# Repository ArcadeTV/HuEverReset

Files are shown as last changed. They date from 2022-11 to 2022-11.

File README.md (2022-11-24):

## HuEverReset
InGame-Reset for PC Engine with support for TurboEverdrive v1-v2.5

_*Important!*_ - Please consider waiting until everything is confirmed working.

### v20221109 / ArcadeTV

---

#### Description:
This enables an InGame-Reset by pressing a button-combo on the controller that also works with TurboEverdrive to get back to the menu.
It is designed for the white japanese PC Engine console but can be easily adapted to any PC Engine system if you know which pins of the controller-input-socket to connect to the pcb. Optionally you can use a piezo speaker for acoustic feedback upon triggering a reset.

---

#### Parts

| Part | Value | Device | Package |
| :--- | :--- | :--- | :--- |
| CB1  | 100nF | C-USC0805 | C0805 |
| C1 | 220uF | CPOL-USC/6032-28R| C/6032-28R |
| D1 | RB168VWM-40TR | RB168VWM-40TR | RB168VWM40TR |
| IC1  | ATTINY84V-10SSUR | ATTINY84V-10SSUR | SOIC127P600X175-14N |
| IC2  | KA78R05CTU_NL | KA78R05 | TO-220-4 |
| R1 | 20K | R-US_R0805 | R0805 |
| R2 | 10K | R-US_R0805 | R0805 |
| R3 | 220 | R-US_R0805 | R0805 |
| HDR  | 3-Pin Header 2.54mm | Pinheader | Pinheader 2.54mm |

Optionally, a piezo speaker like the [KPM-1205A](https://datasheetspdf.com/pdf/868392/Ningbo/KPM-1205A/1). A 220 Ohms resistor is recommended on the positive leg for attenuation. You can also wire a switch to the pads of J1 if you want to toggle this feature on and off.

Also optional a 5V Common Cathode LED can be used for visual feedback. It's lit constantly until the button combo is pressed, then it flashes to indicate that a reset will occur if the combo is pressed longer and finally it goes off while the reset is performed.

Here's a [BOM file in Excel format](https://github.com/ArcadeTV/HuEverReset/raw/main/BOM_HuEverReset_Mouser.xlsx) that you can use to order parts at Mouser. It does not include the KA78R05 regulator, LED and piezo speaker. Also please note that due to a general chip shortage you may have to source the ATtiny84 somewhere else.

---

#### Installation:
See the [wiki](https://github.com/ArcadeTV/HuEverReset/wiki)

---

#### Technical:
Since a TurboEverdrive v1 to v2.5 is not listening to a hard reset (/RESET), implementing an IngameReset that is triggered upon pressing a button-combo on the controller is not possible. This mod solves that problem by replacing the 7805 regulator with a KA78R05 that has a switchable output. So, instead of pulling the /RESET line of the PC Engine LOW, this mod aims to cut the power of the system for 1 second and turning it back on. This ensures that the menu of the TurboEverdrive is displayed. The pcb consists of 2 different layouts including a little POWER BOARD for making the replacement of the power-regulator a breeze.

---

#### Microcontroller:
```
ATtiny84 ----------------
                          _____
            VCC  (  ) 01-|°    |-14 (  ) GND
Jmp: Use Speaker (10) 02-|     |-13 (00) ENABLE (MiniDin 7)
     Speaker (+) (09) 03-|     |-12 (01) D3: Run, Left (MiniDin 5)
            N.C. (11) 04-|     |-11 (02) D2: Select, Down (MiniDin 4)
             LED (08) 05-|     |-10 (03) D1: II, Right (MiniDin 3)
            N.C. (07) 06-|     |-09 (04) SELECT (MiniDin 6)
          /RESET (06) 07-|_____|-08 (05) D0: I, Up (MiniDin 2)

| Fuses: 
| -----------
| low:   0xE2
| high:  0xD7
| ext.:  0xFF
| lock:  0xFF
```
Please mind that the ATtiny84 microcontroller needs to be programmed
with the provided hex file. If you use the ISP header on the pcb, please do so while the board is unpopulated except for IC1.

---

#### Jumper J1
Enable or Disable the use of a piezo speaker (buzzer).
```
Closed: use
Open: ignore
```
If you connect a piezo speaker for acoustic feedback when a reset is triggered, close J1. You may want to use a resistor on the positive leg of the speaker (e.g. 220 Ohms) if you find it too loud.

---

#### PCB
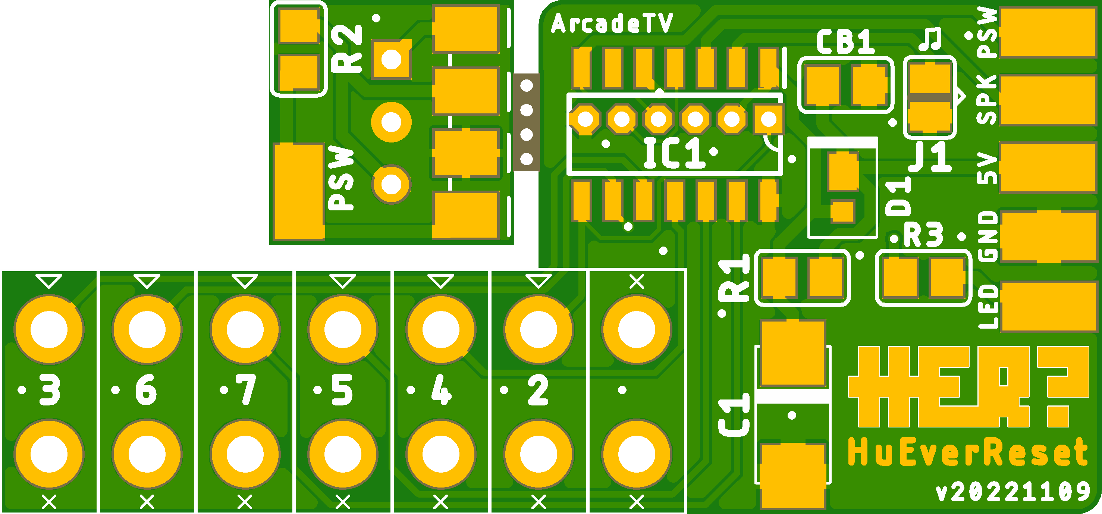
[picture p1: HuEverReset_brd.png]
HuEverReset pcb

Use the provided gerber files to order your pcb from your favorite manufacturer. 
I recommend jlcpcb. When ordering from jlcpcb, fill out the order-form as follows:

```
Different Design: 2
Delivery Format: Panel by Customer
PCB Thickness: 0.8 - 1.0 mm
```

**GERBER** files can be downloaded from the `releases` tab: 

https://github.com/ArcadeTV/HuEverReset/releases/latest

Eagle source files for editing also exist in this repository.

---

#### Thanks

NeoRame, Astrocade & micro

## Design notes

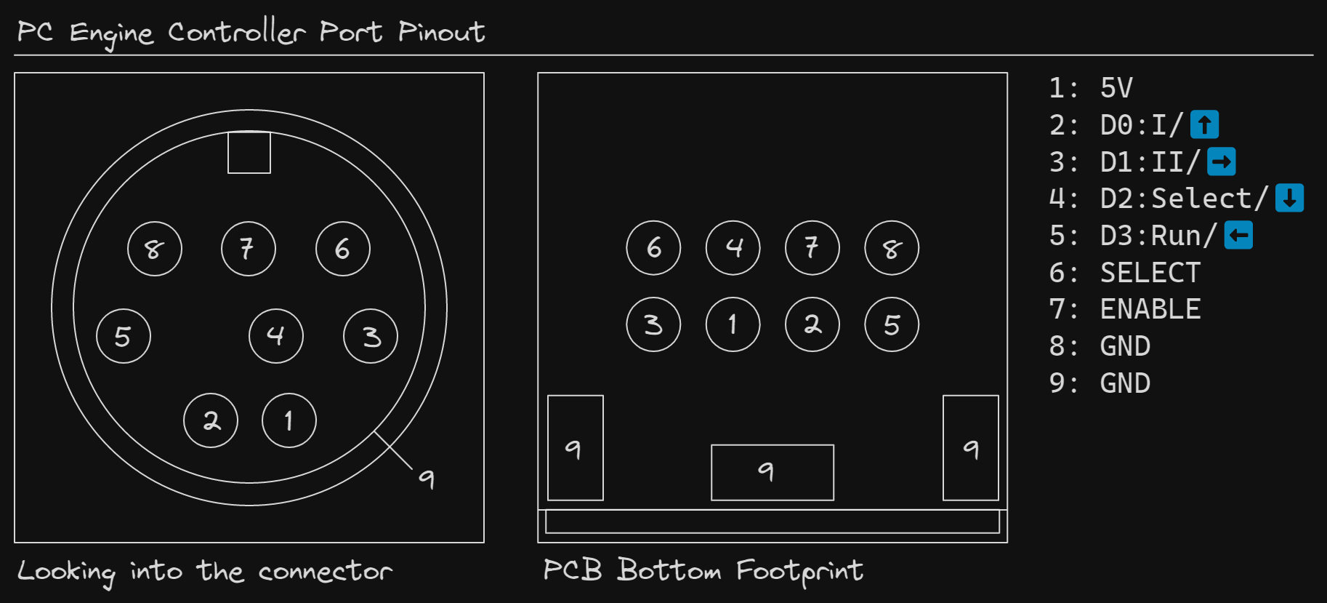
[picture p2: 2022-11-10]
pce_cntrl_port_blk.png

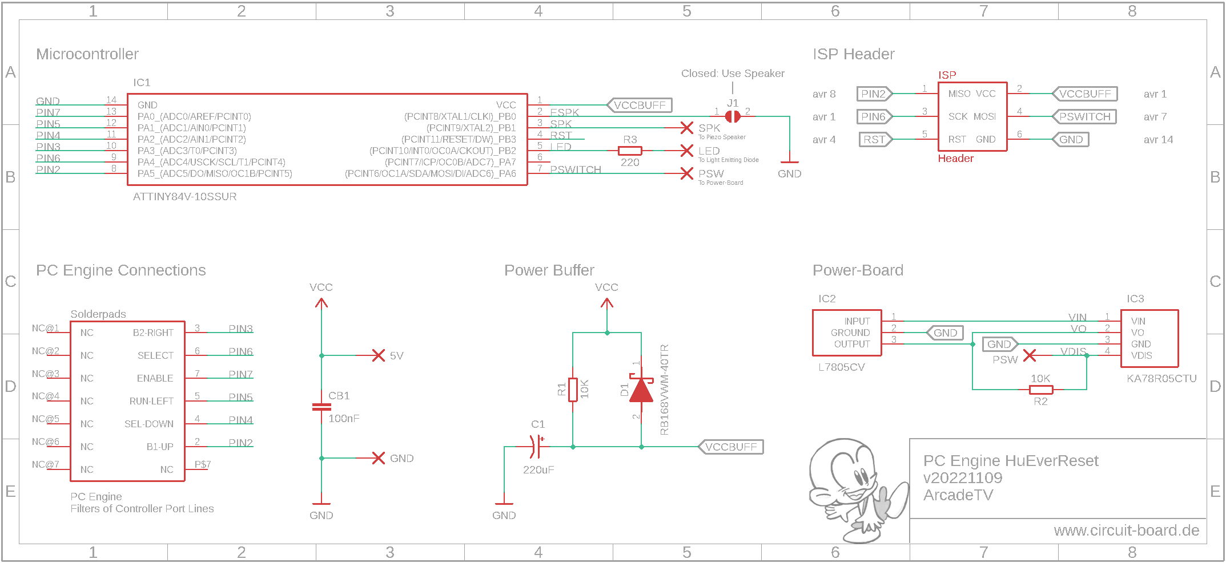
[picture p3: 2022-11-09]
HuEverReset_sch.png

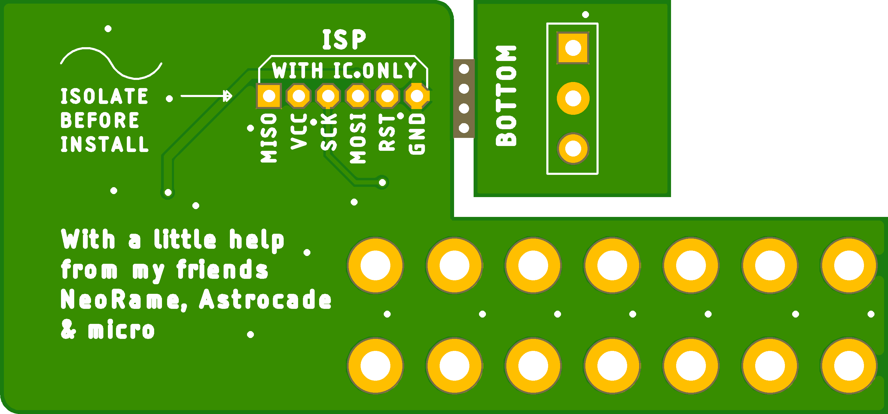
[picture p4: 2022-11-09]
HuEverReset_brd_btm.png

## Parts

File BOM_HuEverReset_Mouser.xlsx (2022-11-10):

Mfr Part Number (Input) | Manufacturer Part Number | Mouser Part Number | Manufacturer Name | Description | Quantity 1 | Unit Price 1 | Quantity 2 | Unit Price 2 | Quantity 3 | Unit Price 3 | Quantity 4 | Unit Price 4 | Quantity 5 | Unit Price 5 | Order Quantity | Order Unit Price | Min./Mult. | Availability | Lead Time in Days | Lifecycle | NCNR | RoHS | Pb Free | Package Type | Datasheet URL | Product Image | Design Risk | Preisangebot Teilnummer
RB168VWM-40TR |  | 755-RB168VWM-40TR |  | D1 | 1 | 0,49 € |  |  |  |  |  |  |  |  | 1 | 0,49 € | 1\1 | 1.944 | 105 | New Product | Nein | Ja | Ja | REEL | https://fscdn.rohm.com/en/products/databook/datasheet/discrete/diode/schottky_barrier/rb168vwm-40tr-e.pdf |  | Das Produkt ist neu und leicht verfügbar. | 755-RB168VWM-40TR
ATTINY84A-SSU |  | 556-ATTINY84A-SSU |  | IC1 | 1 | 1,09 € |  |  |  |  |  |  |  |  | 1 | 1,09 € | 1\1 |  | 484 |  | Nein | Ja | Ja | TUBE | https://www.mouser.com/datasheet/2/268/ATtiny24A_44A_84A_DataSheet_DS40002269A-1928684.pdf |  | Das Produkt hat eine moderate Popularität und ist leicht verfügbar. | 556-ATTINY84A-SSU
T491C227K010AT |  | 80-T491C227K010AT |  | C1 | 1 | 1,83 € |  |  |  |  |  |  |  |  | 1 | 1,83 € | 1\1 | 6.850 | 91 |  | Nein | Ja | Ja | REEL | https://www.mouser.com/datasheet/2/212/1/KEM_T2005_T491-1093550.pdf |  | Das Produkt hat eine hohe Popularität und ist leicht verfügbar. | 80-T491C227K010AT
C0805T104K5RACTU |  | 80-C0805T104K5RACTU |  | CB1 | 1 | 1,12 € |  |  |  |  |  |  |  |  | 1 | 1,12 € | 1\1 | 5.075 | 125 |  | Nein | Ja | Ja | REEL | https://www.mouser.com/datasheet/2/212/KEM_C1027_X7R_COTS_SMD-1099449.pdf |  | Das Produkt hat eine moderate Popularität und ist leicht verfügbar. | 80-C0805T104K5RACTU
68797-403HLF |  | 649-68797-403HLF |  | HDR | 1 | 0,26 € |  |  |  |  |  |  |  |  | 1 | 0,26 € | 1\1 | 8.152 | 123 |  | Nein | Ja | Ja | BULK | https://www.mouser.com/datasheet/2/18/68000-1266375.pdf |  | Das Produkt hat eine moderate Popularität und ist leicht verfügbar. | 649-68797-403HLF
ERJ-PB6B2002V |  | 667-ERJ-PB6B2002V |  | R1 | 1 | 0,40 € |  |  |  |  |  |  |  |  | 1 | 0,40 € | 1\1 | 17.048 | 182 |  | Nein | Ja | Nein | REEL | https://www.mouser.com/datasheet/2/315/AOA0000C328-1530132.pdf |  | Das Produkt hat eine hohe Popularität und ist leicht verfügbar. | 667-ERJ-PB6B2002V
ERJ-PB6B1002V |  | 667-ERJ-PB6B1002V |  | R2 | 1 | 0,40 € |  |  |  |  |  |  |  |  | 1 | 0,40 € | 1\1 | 34.951 | 182 |  | Nein | Ja | Nein | REEL | https://www.mouser.com/datasheet/2/315/AOA0000C328-1530132.pdf |  | Das Produkt hat eine hohe Popularität und ist leicht verfügbar. | 667-ERJ-PB6B1002V
ERJ-PB6B2200V |  | 667-ERJ-PB6B2200V |  | R3 | 1 | 0,40 € |  |  |  |  |  |  |  |  | 1 | 0,40 € | 1\1 | 7.845 | 182 |  | Nein | Ja | Nein | REEL | https://www.mouser.com/datasheet/2/315/AOA0000C328-1530132.pdf |  | Das Produkt hat eine hohe Popularität und ist leicht verfügbar. | 667-ERJ-PB6B2200V

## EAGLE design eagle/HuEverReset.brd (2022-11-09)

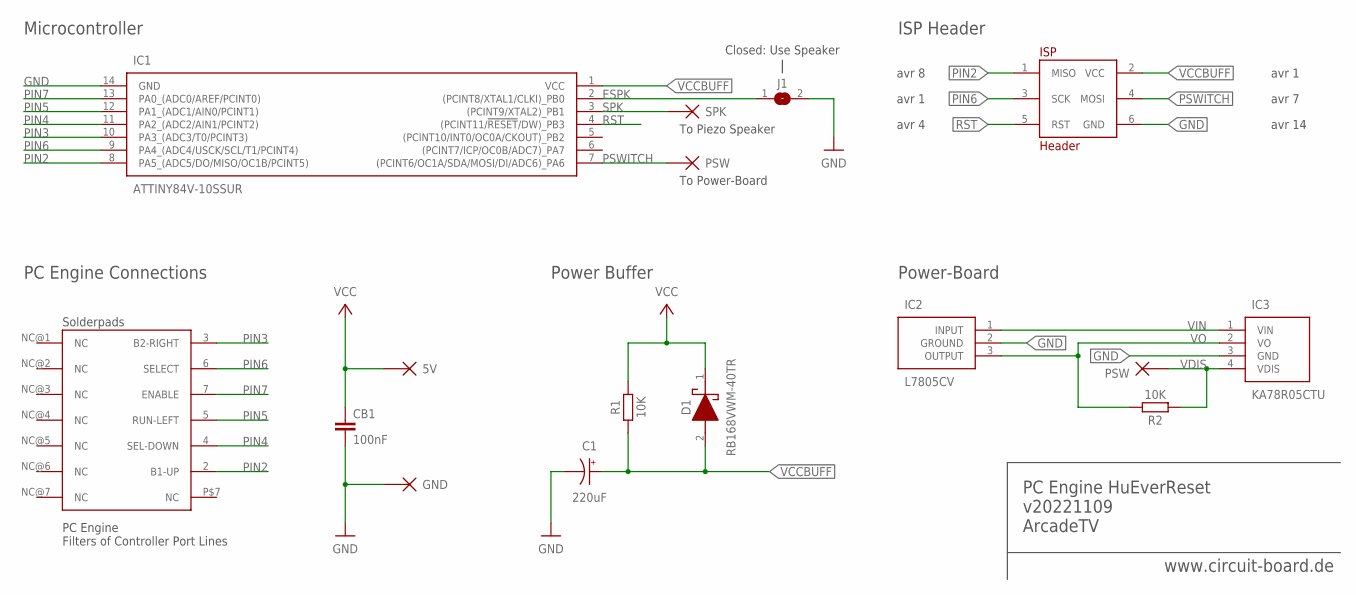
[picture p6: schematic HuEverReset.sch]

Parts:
C1: 220uF; C/6032-28R
CB1: 100nF; Z0805
D1: RB168VWM-40TR; RB168VWM40TR
IC1: ATTINY84V-10SSUR; SOIC127P600X175-14N
IC2: L7805CV; TO255P460X1020X2008-3P
IC3: KA78R05CTU; PADS
ISP: Header; TINY
J1: SJ
P1: 5V; PADS
P2: GND; PADS
P3: PSW; PADS
P4: SPK; PADS
R1, R2: 10K; Z0805
U$1: PCE-CNTRL-FILTERS
U$2: PSW; PADS

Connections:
ESPK: IC1.2 ((PCINT8/XTAL1/CLKI)_PB0), J1.1
GND: C1.-, CB1.2, IC1.14 (GND), IC2.2 (GROUND), IC3.3 (GND), ISP.6 (GND), J1.2, P2.P$1
PIN2: IC1.8 (PA5_(ADC5/DO/MISO/OC1B/PCINT5)), ISP.1 (MISO), U$1.2 (B1-UP)
PIN3: IC1.10 (PA3_(ADC3/T0/PCINT3)), U$1.3 (B2-RIGHT)
PIN4: IC1.11 (PA2_(ADC2/AIN1/PCINT2)), U$1.4 (SEL-DOWN)
PIN5: IC1.12 (PA1_(ADC1/AIN0/PCINT1)), U$1.5 (RUN-LEFT)
PIN6: IC1.9 (PA4_(ADC4/USCK/SCL/T1/PCINT4)), ISP.3 (SCK), U$1.6 (SELECT)
PIN7: IC1.13 (PA0_(ADC0/AREF/PCINT0)), U$1.7 (ENABLE)
PSWITCH: IC1.7 ((PCINT6/OC1A/SDA/MOSI/DI/ADC6)_PA6), ISP.4 (MOSI), P3.P$1
RST: IC1.4 ((PCINT11/!RESET!/DW)_PB3), ISP.5 (RST)
SPK: IC1.3 ((PCINT9/XTAL2)_PB1), P4.P$1
VCC: CB1.1, D1.1 (K), P1.P$1, R1.2
VCCBUFF: C1.+, D1.2 (A), IC1.1 (VCC), ISP.2 (VCC), R1.1
VDIS: IC3.4 (VDIS), R2.1, U$2.P$1
VIN: IC2.1 (INPUT), IC3.1 (VIN)
VO: IC2.3 (OUTPUT), IC3.2 (VO), R2.2

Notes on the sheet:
PC Engine HuEverReset v20221109 ArcadeTV
To Power-Board
Solderpads
PC Engine Filters of Controller Port Lines
Power-Board
To Piezo Speaker
ISP Header
avr 4
avr 1
avr 8
avr 7
avr 14
Power Buffer
PC Engine Connections
Microcontroller
www.circuit-board.de
Closed: Use Speaker

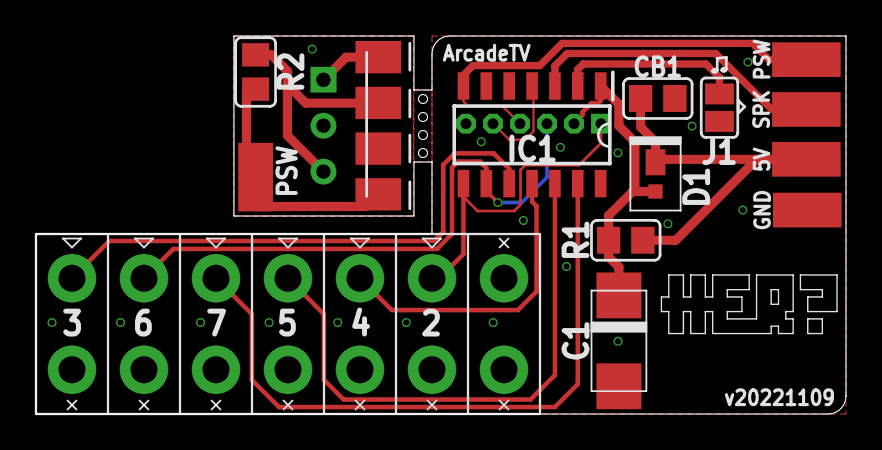
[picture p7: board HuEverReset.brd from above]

Board: 2 copper layers, 45.0 x 21.0 mm, 16 parts (0 on the bottom side), 16 nets.

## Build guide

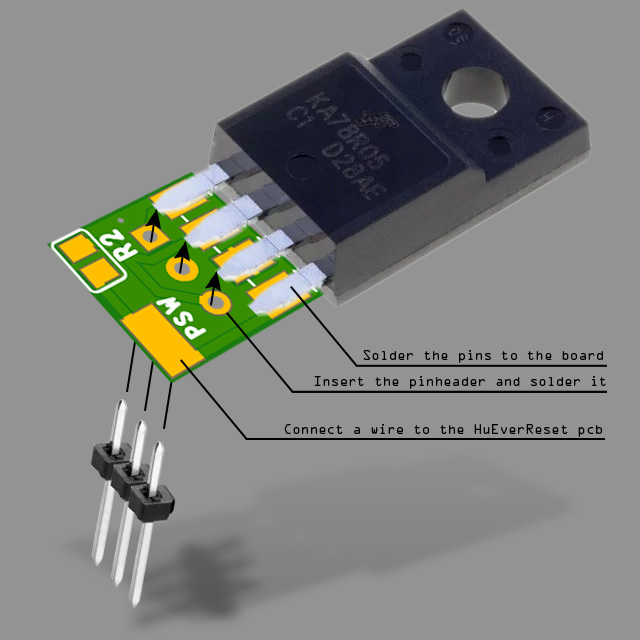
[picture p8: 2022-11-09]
HuEverReset_install_02.jpg

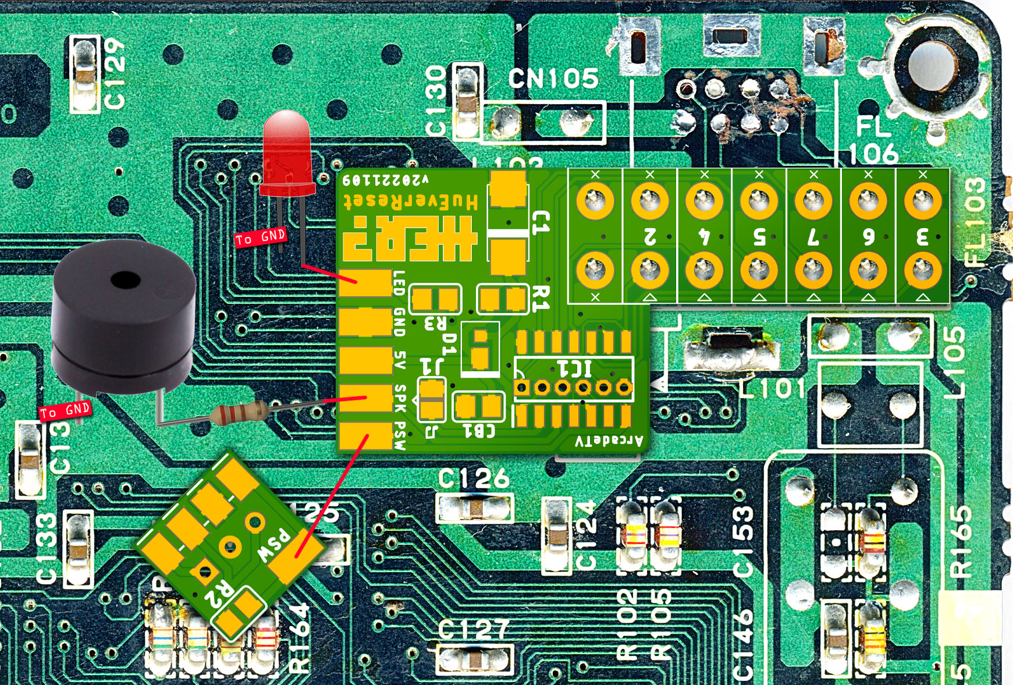
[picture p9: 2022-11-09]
HuEverReset_install_01.jpg

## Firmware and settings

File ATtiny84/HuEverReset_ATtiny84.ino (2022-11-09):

/* 
ATtiny84 ----------------
                          _____
            VCC  (  ) 01-|°    |-14 (  ) GND
Jmp: Use Speaker (10) 02-|     |-13 (00) ENABLE (MiniDin 7)
     Speaker (+) (09) 03-|     |-12 (01) D3: Run, Left (MiniDin 5)
            N.C. (11) 04-|     |-11 (02) D2: Select, Down (MiniDin 4)
             LED (08) 05-|     |-10 (03) D1: II, Right (MiniDin 3)
            N.C. (07) 06-|     |-09 (04) SELECT (MiniDin 6)
          /RESET (06) 07-|_____|-08 (05) D0: I, Up (MiniDin 2)

| Fuses: 
| -----------
| low:   0xE2
| high:  0xD7
| ext.:  0xFF
| lock:  0xFF

----------------------------------------------------------------------------------------------------------

Description:
Source Code for the ATtiny84 avr of the project "HuEverReset".
https://github.com/ArcadeTV/HuEverReset/
The avr is listening for joypad inputs.
When the button-combo I+II+RUN+SELECT is held for 2 seconds,
an active-low reset signal is sent from pin 7.

*/

// S-E-T-U-P: --------------------------------------------------------------------------------------------
// Change these settings to your needs

bool testOnArduino = false; // For development purposes set this to true.
                            // Useful for testing outside a real PC Engine console.
                            // Pins 9 (SELECT) and 13 (ENABLE) will become OUTPUTS and will always be LOW!
bool enableSerial = false;

// P-I-N-S: ----------------------------------------------------------------------------------------------
const byte CTRL2 = 5;  // D0: I, Up
const byte CTRL3 = 3;  // D1: II, Right
const byte CTRL4 = 2;  // D2: Select, Down
const byte CTRL5 = 1;  // D3: Run, Left
const byte CTRL6 = 4;  // SELECT
const byte CTRL7 = 0;  // ENABLE

const byte RESET = 6;  // RESET OUT (active low)

const byte useBuzzer = 10;
const int buzzer = 9;

const int LED = 8;
// -------------------------------------------------------------------------------------------------------

unsigned long keyPrevMillis = 0;
const unsigned long keySampleIntervalMs = 25;
byte longKeyPressCountMax = 80;  // 80 * 25 = 2000 ms
byte longKeyPressCount = 0;

byte prevKeyState = HIGH;  // combo is active low

bool resetInProgress = false;
bool comboActive = false;
int buzzing = HIGH;

void setup() {
  if (enableSerial) {
    Serial.begin(115200);
    Serial.flush();
    Serial.println("Initialized!\n");
  }

  pinMode(useBuzzer, INPUT_PULLUP);
  pinMode(buzzer, OUTPUT);

  pinMode(LED, OUTPUT);
  digitalWrite(LED, HIGH);

  pinMode(RESET, INPUT);  // init RESET pin as input
  pinMode(CTRL2, INPUT);
  pinMode(CTRL3, INPUT);
  pinMode(CTRL4, INPUT);
  pinMode(CTRL5, INPUT);

  if (testOnArduino) {
    pinMode(CTRL6, OUTPUT);
    pinMode(CTRL7, OUTPUT);
  } else {
    pinMode(CTRL6, INPUT);
    pinMode(CTRL7, INPUT);
  }

  digitalWrite(CTRL6, LOW);
  digitalWrite(CTRL7, LOW);
}


byte checkButtonCombo() {

  byte result;

  if (testOnArduino) {
    byte button_I = digitalRead(CTRL2);
    byte button_II = digitalRead(CTRL3);
    byte button_SELECT = digitalRead(CTRL4);
    byte button_RUN = digitalRead(CTRL5);
    result = (button_I | button_II | button_SELECT | button_RUN);
  } else {
    byte button_I = digitalRead(CTRL2);
    byte button_II = digitalRead(CTRL3);
    byte button_SELECT = digitalRead(CTRL4);
    byte button_RUN = digitalRead(CTRL5);
    byte line_SELECT = digitalRead(CTRL6);
    byte line_ENABLE = digitalRead(CTRL7);
    result = (button_I | button_II | button_SELECT | button_RUN | line_SELECT | line_ENABLE);
  }
  return result;
}


// called when button is kept pressed for less than 2 seconds
void shortKeyPress() {
  if (enableSerial) {
    Serial.println(" -> Combo too short!");
  }
}


// called when button is kept pressed for more than 2 seconds
void longKeyPress() {
  if (enableSerial) {
    Serial.println(" -> RESET has been triggered!");
  }
}


// called when key goes from not pressed to pressed
void keyPress() {
  if (enableSerial) {
    Serial.flush();
    Serial.print("Combo detected!");
  }
  longKeyPressCount = 0;
  comboActive = true;
}


// called when key goes from pressed to not pressed
void keyRelease() {
  if (enableSerial) {
    Serial.flush();
    Serial.print("\nCombo released.");
  }

  if (longKeyPressCount >= longKeyPressCountMax) {
    longKeyPress();
  } else {
    shortKeyPress();
  }

  if (!resetInProgress) {
    digitalWrite(LED, HIGH);
  }

  comboActive = false;
}

void performReset() {
  if (enableSerial) {
    Serial.println("\nRESETTING!");
  }

  buzzing = digitalRead(useBuzzer);

  if (buzzing == LOW) {
    // alert upcoming reset:
    digitalWrite(LED, LOW);
    tone(buzzer, 2220);
    delay(100);

    digitalWrite(LED, HIGH);
    tone(buzzer, 1400);
    delay(100);

    digitalWrite(LED, LOW);
    tone(buzzer, 1675);
    delay(100);

    digitalWrite(LED, HIGH);
    tone(buzzer, 2220);
    delay(100);

    noTone(buzzer);
  }

  digitalWrite(LED, LOW);

  // send /RESET signal:
  pinMode(RESET, OUTPUT);
  delay(2000);
  pinMode(RESET, INPUT);

  digitalWrite(LED, HIGH);
}

void loop() {
  if (millis() - keyPrevMillis >= keySampleIntervalMs) {

    keyPrevMillis = millis();
    byte currKeyState = checkButtonCombo();

    if ((prevKeyState == HIGH) && (currKeyState == LOW)) {

      keyPress();

    } else if ((prevKeyState == LOW) && (currKeyState == HIGH)) {

      keyRelease();
      resetInProgress = false;

    } else if (currKeyState == LOW) {
      longKeyPressCount++;

      // LED flashing while holding button combo:
      if (longKeyPressCount <= 10) {
        digitalWrite(LED, LOW);
      } else if (longKeyPressCount > 10 && longKeyPressCount <= 20) {
        digitalWrite(LED, HIGH);
      } else if (longKeyPressCount > 20 && longKeyPressCount <= 30) {
        digitalWrite(LED, LOW);
      } else if (longKeyPressCount > 30 && longKeyPressCount <= 40) {
        digitalWrite(LED, HIGH);
      } else if (longKeyPressCount > 40 && longKeyPressCount <= 50) {
        digitalWrite(LED, LOW);
      } else if (longKeyPressCount > 50 && longKeyPressCount <= 60) {
        digitalWrite(LED, HIGH);
      } else if (longKeyPressCount > 60 && longKeyPressCount <= 70) {
        digitalWrite(LED, LOW);
      } else if (longKeyPressCount > 70 && longKeyPressCount <= 80) {
        digitalWrite(LED, HIGH);
      }

      if (longKeyPressCount >= longKeyPressCountMax && !resetInProgress) {

        resetInProgress = true;
        performReset();
      }
    }
    prevKeyState = currKeyState;
  }
}
